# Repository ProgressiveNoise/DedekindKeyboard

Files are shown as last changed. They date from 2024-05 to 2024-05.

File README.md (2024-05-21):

# Dedekind, inspired by Cantor

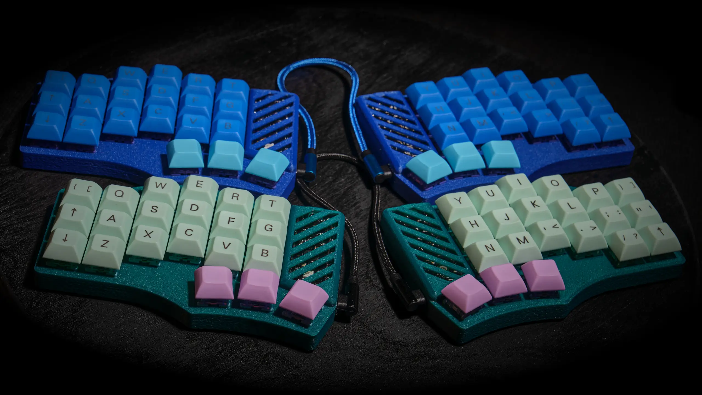
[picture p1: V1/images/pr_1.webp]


- Infinite set of silly mathematical jokes.

- Permissive Open Hardware Licence - do whatever you want with it.

- Not just PCBs, this repo contains STEP for a decent and easy to print case.
  Your build will be very solid.

- Reversible, no need to order 10 boards.

- MX Hotswap.

- Robust through-hole USB-C socket for interconnection:

    - Very reliable.

    - Does not fry MCU I/Os by design.

    - Cables are available in every shop on the planet.

- Optional extra protection circuit.

- RP2040 is a powerful and well-supported MCU.

- Easy to source parts.

This keyboard is compact, reliable, and relatively easy to build. It is
diodeless, the protection circuit is optional. Only the TH USB-C connector
could be an annoyance for an inexperienced builder, but that’s it. Everything
else should be smooth.

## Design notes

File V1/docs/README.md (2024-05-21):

## BOM

- 2 PCBs - necessary
- 2 Pico-like MCU boards - necessary
- 2 [USB-C TH connectors](https://www.aliexpress.com/item/4001044452764.html) - necessary
- 42 Kailh or Gateron MX sockets - necessary
- 2 0805 resistors - optional
- 2 323 protection devices - optional
- 4 20 pin sockets - optional

## PSBs
Everything is straightforward.

First, solder the MX sockets.

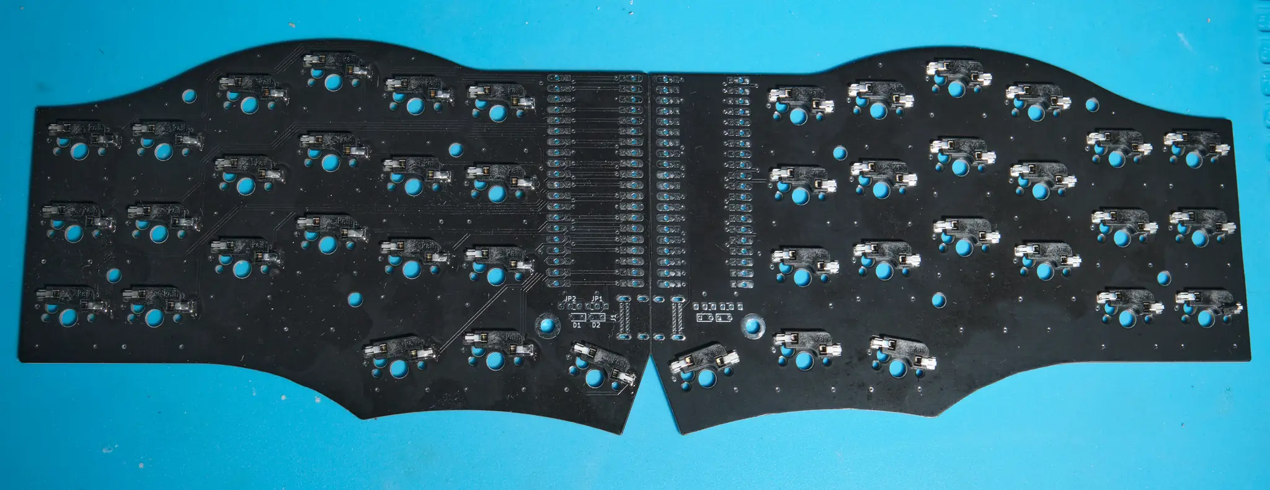
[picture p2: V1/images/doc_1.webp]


Then, solder protection circuit. You need TVS/ESD protection for 3.3V data
lines (I use the UCLAMP3301D) and some 0805 resistors. Their value is not very
important. Everything small enough, let’s say from 200 to 2k, should be fine.
You can skip this step, since the USB-C is a much safer connector than the
usual TRRS. If you decide to do so, just put jumpers instead of the resistors.
The white lines mark the default placement for the resistors/jumpers. Do not
forget about protection devices’ polarity as well.

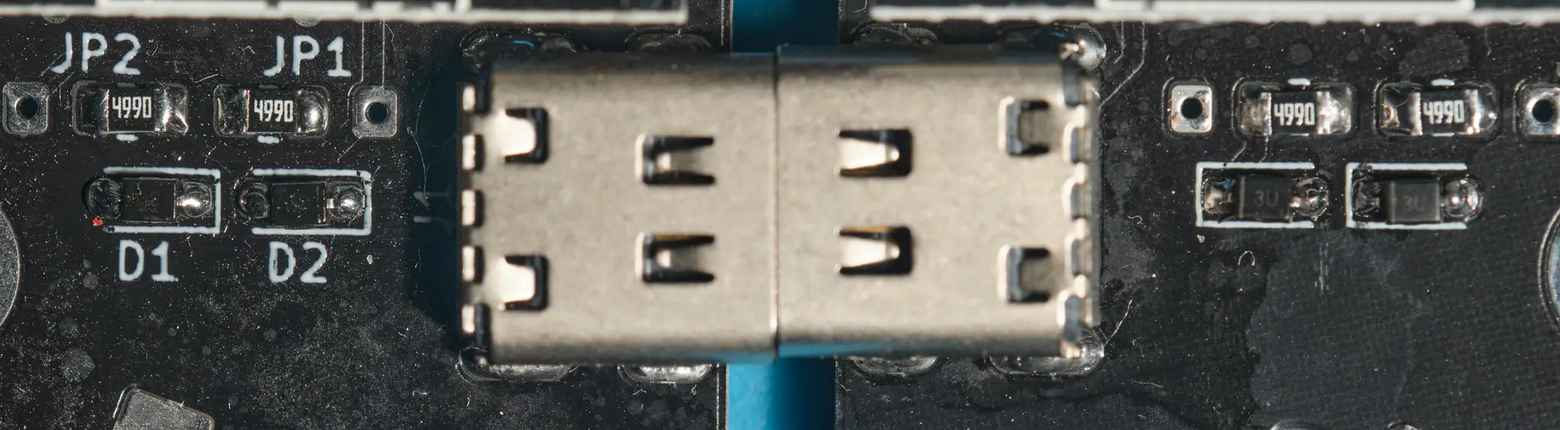
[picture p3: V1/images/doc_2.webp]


Solder the USB-C connector. Its “legs” may be too short for a thick PCBs, but
this is not a big issue. I fill the holes with soldering paste and then solder
“non-ground” part of the connector with a soldering iron. Good flux is your
best friend here! After that, use a slightly overheated iron for the ground
part of the connector, since the connector and copper pour suck a lot of heat.

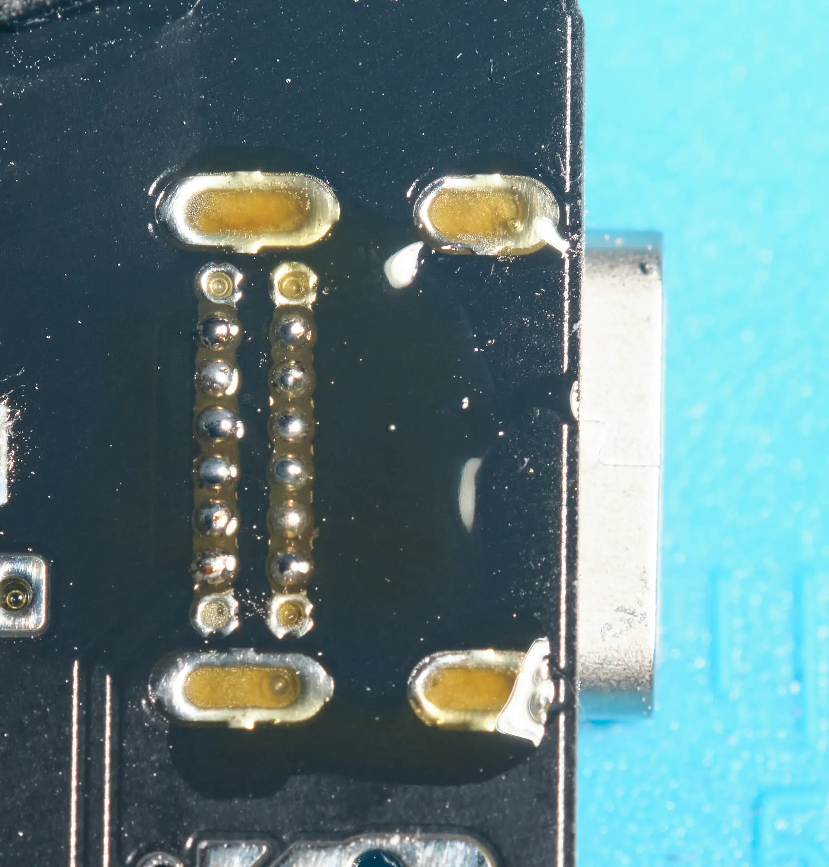
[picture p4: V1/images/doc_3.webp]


This is how it should look like in the end. This type of connection is very
safe and robust.

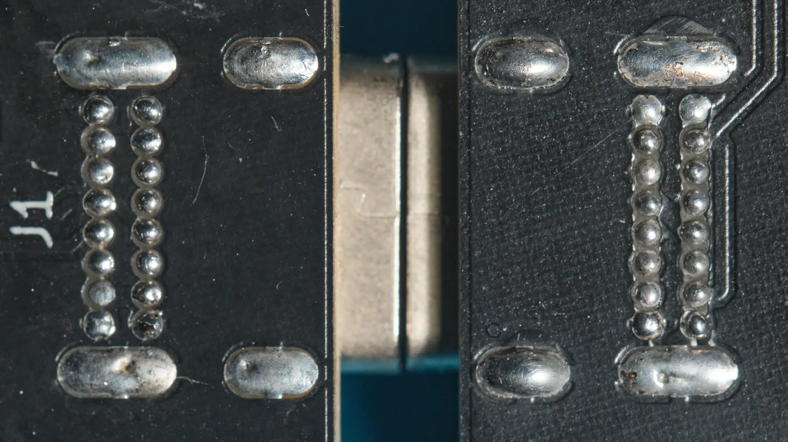
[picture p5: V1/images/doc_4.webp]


Then solder your MCU boards. The “official” case is designed for the 3.5 mm
sockets, but you can use whatever you like, of course, or no sockets at all.

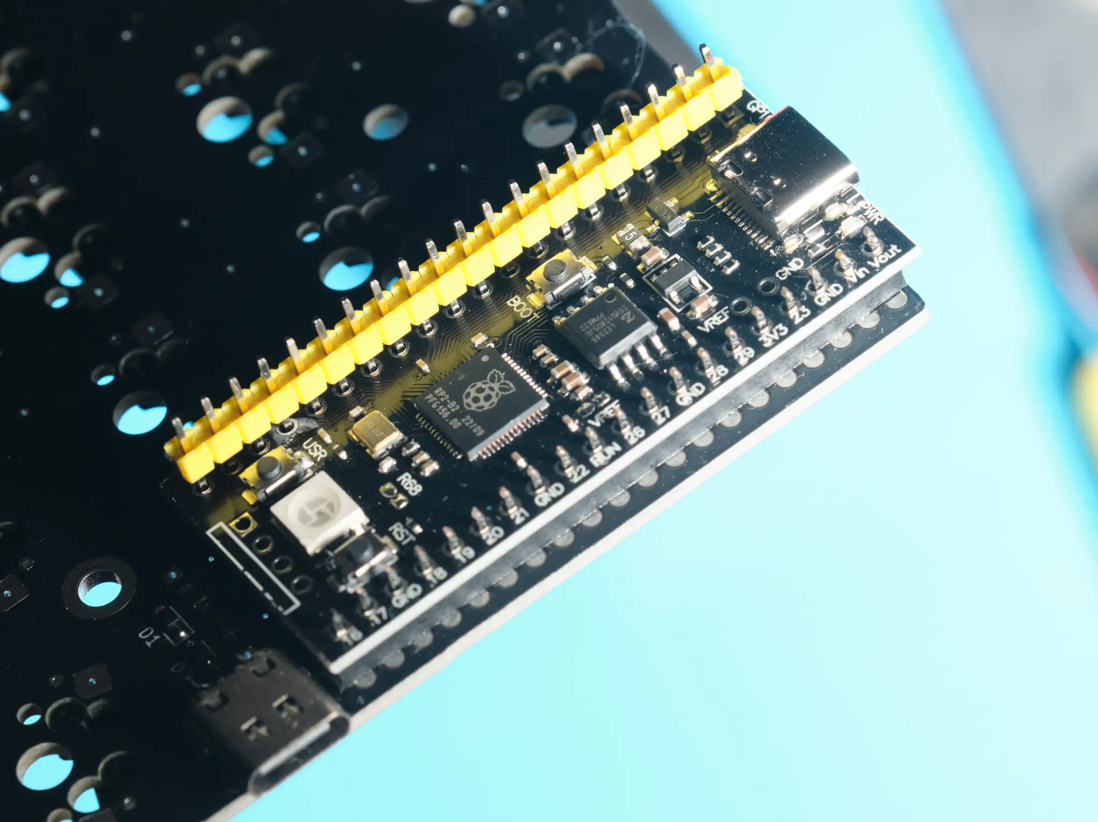
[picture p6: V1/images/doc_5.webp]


This is how it should look like from the top. 

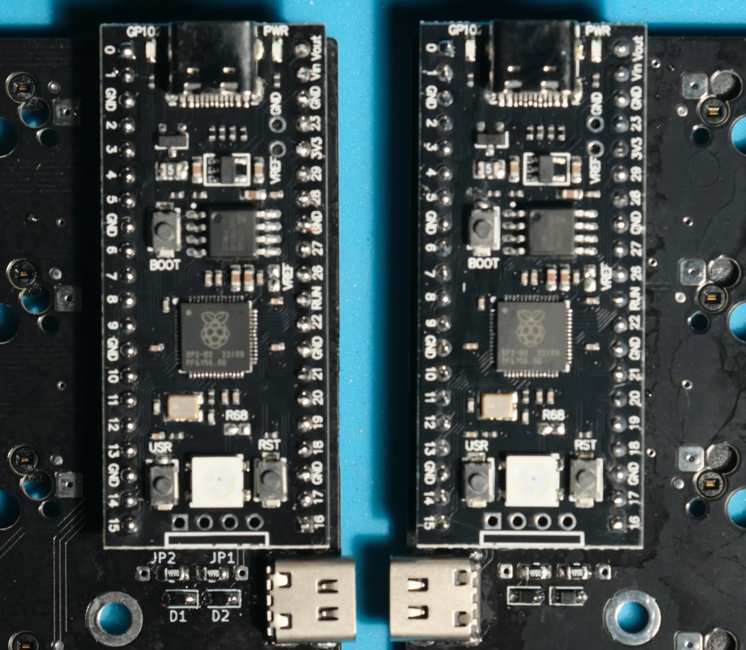
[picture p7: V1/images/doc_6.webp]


On the bottom, and on the bottom only, close the jumpers. Conical bent type
tips are particularly useful for it.

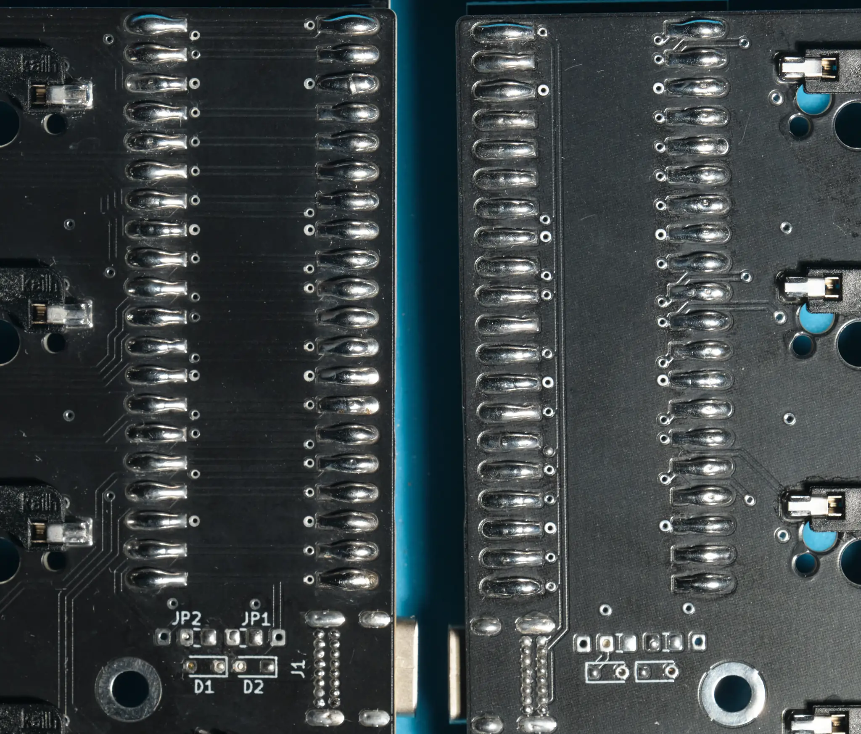
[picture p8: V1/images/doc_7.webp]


Now it is time to clean everything up.
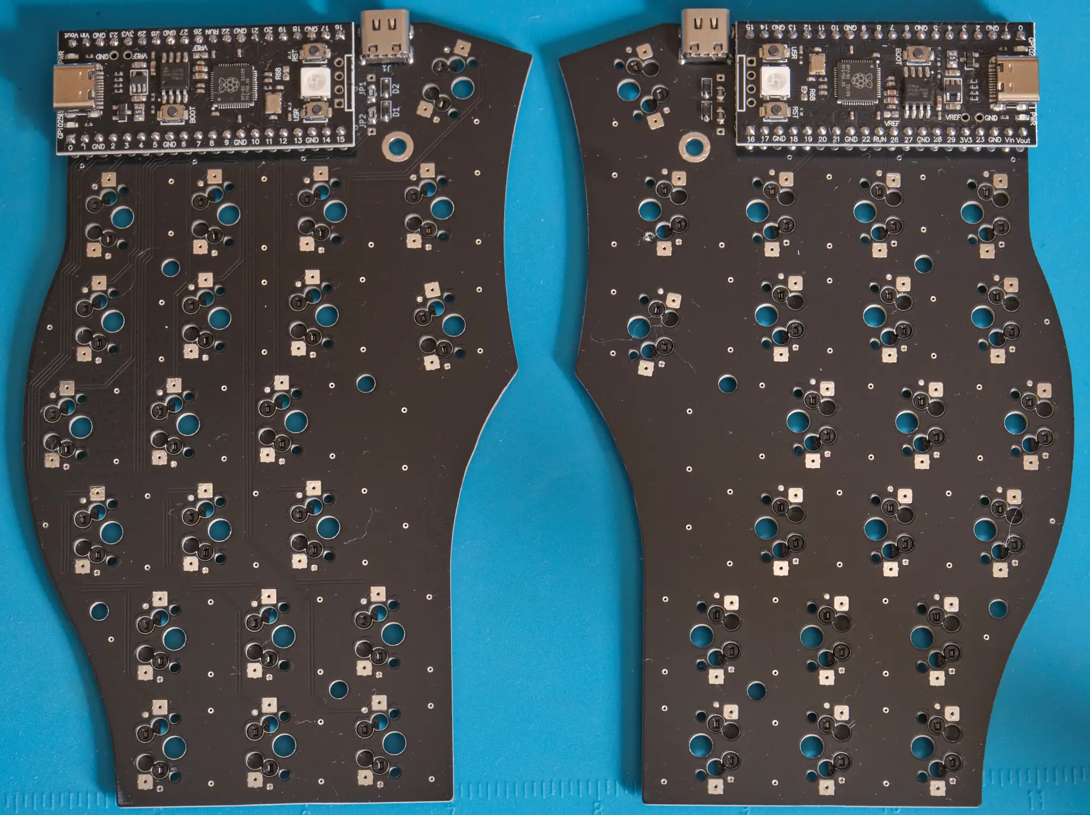
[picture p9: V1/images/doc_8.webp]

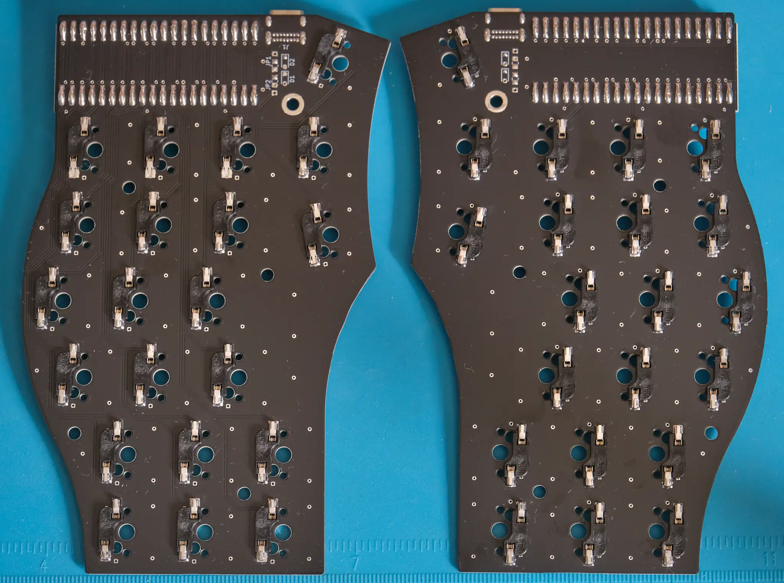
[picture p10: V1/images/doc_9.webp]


## Firmware

At the moment, only [KMK](https://kmkfw.io/) is supported since it is what I
use. I will add QMK support soon.

- Drag and drop [CircuitPyton for the Pico](https://circuitpython.org/board/raspberry_pi_pico/).
  [Official guide](https://learn.adafruit.com/welcome-to-circuitpython/installing-circuitpython).
- Copy the kmk directory from the [official repo](https://github.com/KMKfw/kmk_firmware) to 
    the CIRCUITPY “flash drive”.
- Copy kb.py and main.py from [this repo](../kmk/) to the same place.
- Then rename the “drives” as “DEDR” for the right half and “DEDL” for the left
    half.

The keyboard should work, but its configuration is beyond the scope of
this guide. Follow the official documentation for KMK and CP.

## Case

I provide an “official“ case for this keyboard. It is a straightforward print,
but the frame around the MCU board is susceptible to warping, so use
warp-preventing settings in your slicer, or even a brim. It is better to be
safe than sorry. The MCU cover is optional. Glue it to the top case if you want
to use it.

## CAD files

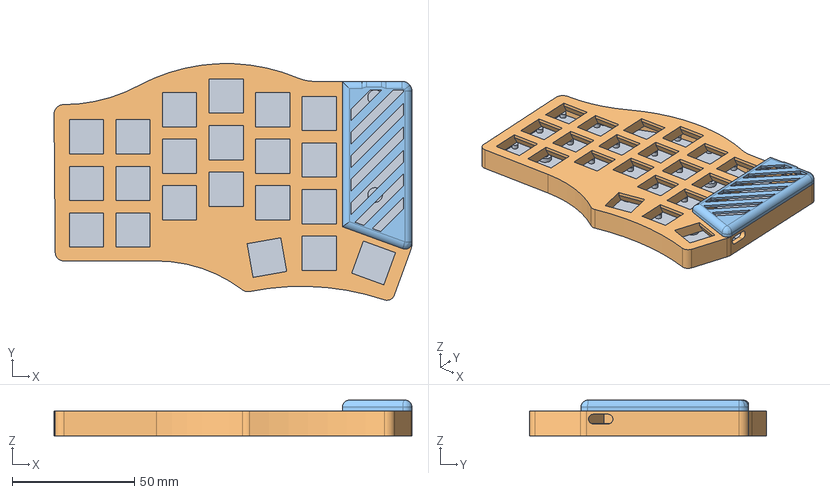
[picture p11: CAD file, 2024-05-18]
V1/case/Dedekind_MX_Case_V1.step
146.5 x 96.8 x 14.7 mm
Bottom
Plate
MCU Cover

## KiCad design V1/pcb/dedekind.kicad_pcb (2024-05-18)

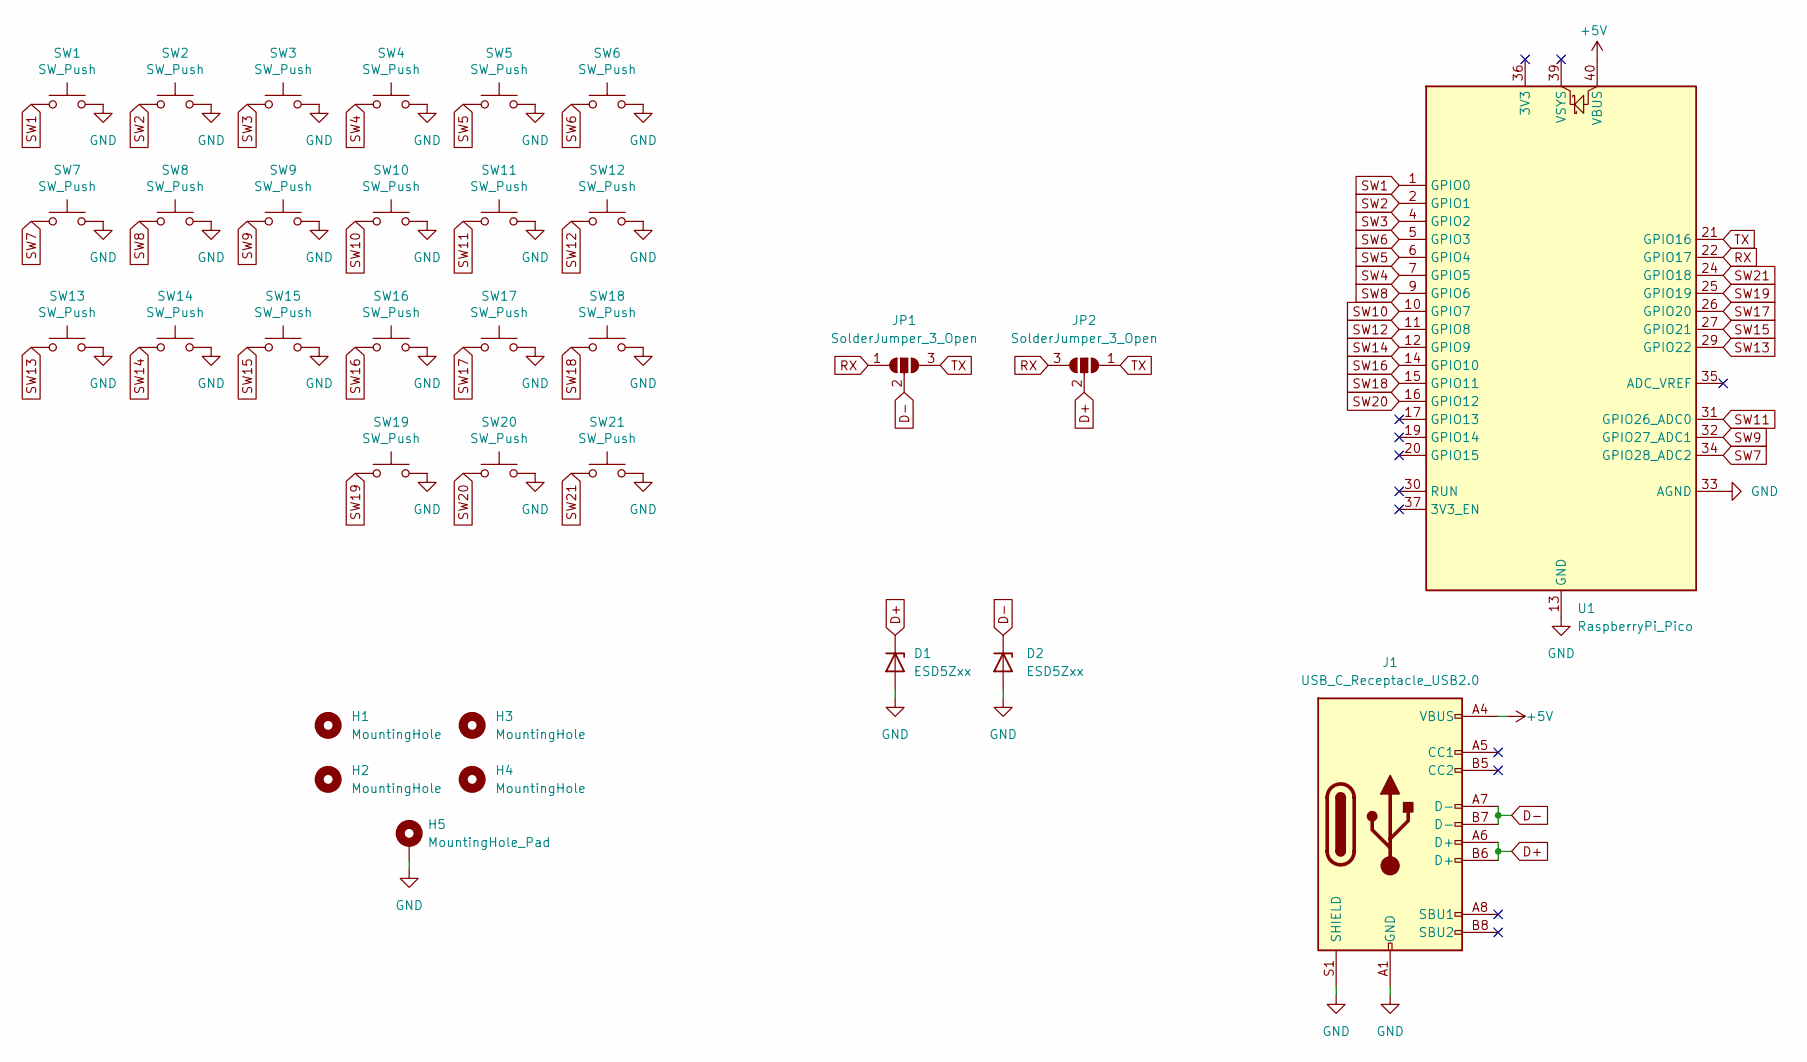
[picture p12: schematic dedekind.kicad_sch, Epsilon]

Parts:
D1, D2: ESD5Zxx; D_SOD-323_TH_HandSoldering
H1, H2, H3, H4: MountingHole; MountingHole_3.2mm_M3
H5: MountingHole_Pad; MountingHole_3.2mm_M3_DIN965_Pad
J1: USB_C_Receptacle_USB2.0; USB_C_Receptacle_JBL
JP1, JP2: SolderJumper_3_Open; R_0805_2012Metric_Pad1.20x1.40mm_Jumper_HandSolder
SW1, SW2, SW3, SW4, SW5, SW6, SW7, SW8, SW9, SW10, SW11, SW12, SW13, SW14, SW15, SW16, SW17, SW18, SW19, SW20, SW21: SW_Push; SW_Hotswap_Kailh_MX_DS_1.00u
U1: RaspberryPi_Pico; RaspberryPi_Pico_Common_Reversable

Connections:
+5V: J1.A4 (VBUS), J1.A9 (VBUS), J1.B4 (VBUS), J1.B9 (VBUS), U1.40 (VBUS)
D+: D1.1 (K), J1.A6 (D+), J1.B6 (D+), JP2.2 (C)
D-: D2.1 (K), J1.A7 (D-), J1.B7 (D-), JP1.2 (C)
GND: D1.2 (A), D2.2 (A), H5.1, J1.A1 (GND), J1.A12 (GND), J1.B1 (GND), J1.B12 (GND), J1.S1 (SHIELD), SW1.2, SW2.2, SW3.2, SW4.2, SW5.2, SW6.2, SW7.2, SW8.2, SW9.2, SW10.2, SW11.2, SW12.2, SW13.2, SW14.2, SW15.2, SW16.2, SW17.2, SW18.2, SW19.2, SW20.2, SW21.2, U1.3 (GND), U1.8 (GND), U1.13 (GND), U1.18 (GND), U1.23 (GND), U1.28 (GND), U1.33 (AGND), U1.38 (GND)
RX: JP1.1 (A), JP2.3 (B), U1.22 (GPIO17)
SW1: SW1.1, U1.1 (GPIO0)
SW2: SW2.1, U1.2 (GPIO1)
SW3: SW3.1, U1.4 (GPIO2)
SW4: SW4.1, U1.7 (GPIO5)
SW5: SW5.1, U1.6 (GPIO4)
SW6: SW6.1, U1.5 (GPIO3)
SW7: SW7.1, U1.34 (GPIO28_ADC2)
SW8: SW8.1, U1.9 (GPIO6)
SW9: SW9.1, U1.32 (GPIO27_ADC1)
SW10: SW10.1, U1.10 (GPIO7)
SW11: SW11.1, U1.31 (GPIO26_ADC0)
SW12: SW12.1, U1.11 (GPIO8)
SW13: SW13.1, U1.29 (GPIO22)
SW14: SW14.1, U1.12 (GPIO9)
SW15: SW15.1, U1.27 (GPIO21)
SW16: SW16.1, U1.14 (GPIO10)
SW17: SW17.1, U1.26 (GPIO20)
SW18: SW18.1, U1.15 (GPIO11)
SW19: SW19.1, U1.25 (GPIO19)
SW20: SW20.1, U1.16 (GPIO12)
SW21: SW21.1, U1.24 (GPIO18)
TX: JP1.3 (B), JP2.1 (A), U1.21 (GPIO16)

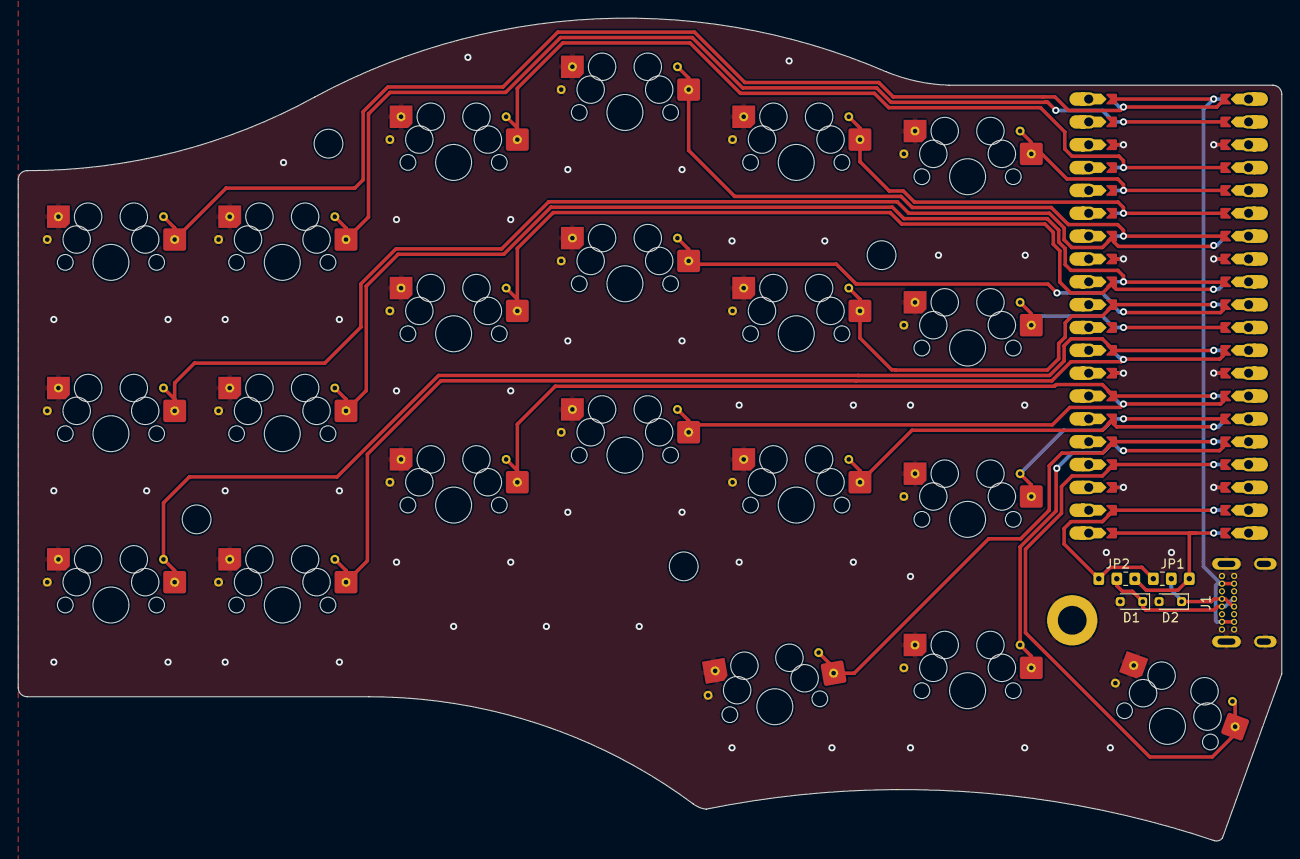
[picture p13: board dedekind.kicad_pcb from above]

Board: 2 copper layers, 140.5 x 91.5 mm, 32 parts (0 on the bottom side), 27 nets.

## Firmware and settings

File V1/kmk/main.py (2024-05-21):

import board

from kb import KMKKeyboard, is_right

from kmk.keys import KC
from kmk.modules.layers import Layers
from kmk.modules.split import Split, SplitSide

from kmk.modules.holdtap import HoldTap
from kmk.modules.combos import Combos, Chord
from kmk.handlers.sequences import simple_key_sequence as sks

keyboard = KMKKeyboard()

# Split
split_side = SplitSide.RIGHT if is_right else SplitSide.LEFT

split = Split(
    split_side=split_side,
    split_target_left=True,
    uart_interval=20,
    data_pin=board.GP17,  # RX
    data_pin2=board.GP16,  # TX
    uart_flip=False,
    use_pio=False,
)

keyboard.modules.append(split)

# Layers
layers = Layers()
keyboard.modules.append(layers)


# HoldTap
holdtap = HoldTap()
holdtap.tap_time = 175
keyboard.modules.append(holdtap)


# Key names
_______ = KC.TRNS
XXXXXXX = KC.NO

# Mod-taps and layer-taps
# Left hand HRM
A_SFT = KC.HT(KC.A, KC.LSFT)
S_CTR = KC.HT(KC.S, KC.LCTRL)
D_GUI = KC.HT(KC.D, KC.LGUI)
V_VIM = KC.LT(3, KC.V)
F_SYM = KC.LT(1, KC.F)

# Left hand thumbs
SPC_NAV = KC.LT(2, KC.SPC)
TAB_ALT = KC.HT(KC.TAB, KC.LALT)

# Right hand HRM
J_SYM = KC.LT(1, KC.J)
K_GUI = KC.HT(KC.K, KC.RGUI)
L_CTR = KC.HT(KC.L, KC.RCTRL)
M_VIM = KC.LT(3, KC.M)
SCLN_SFT = KC.HT(KC.SCLN, KC.RSFT)

# Right hand thumbs
DEL_ALT = KC.HT(KC.DEL, KC.RALT)
ENT_NAV = KC.LT(2, KC.ENT)
BSP_TMX = KC.LT(4, KC.BSPC)

# Vi-style combos
combos = Combos()

combos.combos = [
    Chord((V_VIM, M_VIM), KC.TG(3)),  # Toggle quasi-Vim layer
    Chord((M_VIM, KC.G), sks((KC.EQL, KC.RABK))),  # => symbol
    Chord((M_VIM, KC.T), sks((KC.MINS, KC.RABK))),  # -> symbol
    Chord((KC.N, KC.G), sks((KC.EXLM, KC.EQL))),  # != symbol
]

keyboard.modules.append(combos)

NXT_W = KC.LCTRL(KC.RIGHT)
PRV_W = KC.LCTRL(KC.LEFT)
O_INP = sks((KC.END, KC.ENT, KC.TO(0)))
I_INP = KC.TO(0)
U_UND = KC.LCTRL(KC.Z)

# TMUX
TM_SCR0 = sks((KC.LCTRL(KC.B), KC.N0))
TM_SCR1 = sks((KC.LCTRL(KC.B), KC.N1))
TM_SCR2 = sks((KC.LCTRL(KC.B), KC.N2))
TM_SCR3 = sks((KC.LCTRL(KC.B), KC.N3))
TM_SCR4 = sks((KC.LCTRL(KC.B), KC.N4))
TM_SCR5 = sks((KC.LCTRL(KC.B), KC.N5))
TM_SCR6 = sks((KC.LCTRL(KC.B), KC.N6))
TM_CRT = sks((KC.LCTRL(KC.B), KC.C))

# fmt: off
keyboard.keymap = [
    [  # QWERTY
       #XXXXXXX,  XXXXXXX,  XXXXXXX,  XXXXXXX,  XXXXXXX,  XXXXXXX,                      XXXXXXX,  XXXXXXX,  XXXXXXX,  XXXXXXX,  XXXXXXX,  XXXXXXX, \
        KC.LBRC,  KC.Q,     KC.W,     KC.E,     KC.R,     KC.T,                         KC.Y,     KC.U,     KC.I,     KC.O,     KC.P,     KC.RBRC, \
        KC.UNDS,  A_SFT,    S_CTR,    D_GUI,    F_SYM,    KC.G,                         KC.H,     J_SYM,    K_GUI,    L_CTR,    SCLN_SFT, KC.DQT,  \
        KC.COLN,  KC.Z,     KC.X,     KC.C,     V_VIM,    KC.B,                         KC.N,     M_VIM,    KC.COMM,  KC.DOT,   KC.SLSH,  KC.BSLS, \
                                                KC.ESC,   SPC_NAV,  TAB_ALT,  DEL_ALT,  ENT_NAV,  BSP_TMX,
    ],
    [  # SYMBOLS
       #XXXXXXX,  XXXXXXX,  XXXXXXX,  XXXXXXX,  XXXXXXX,  XXXXXXX,                      XXXXXXX,  XXXXXXX,  XXXXXXX,  XXXXXXX,  XXXXXXX,  XXXXXXX, \
        KC.SLSH,  KC.HASH,  KC.N4,    KC.N5,    KC.N6,    KC.MINS,                      KC.CIRC,  KC.RCBR,  KC.LCBR,  KC.DLR,   KC.AT,    KC.TILD, \
        KC.PERC,  KC.N0,    KC.N1,    KC.N2,    KC.N3,    KC.EQL,                       KC.GRV,   KC.RPRN,  KC.LPRN,  KC.RBRC,  KC.LBRC,  KC.QUOT, \
        KC.DOT,   KC.ASTR,  KC.N7,    KC.N8,    KC.N9,    KC.PLUS,                      KC.EXLM,  KC.RABK,  KC.LABK,  KC.AMPR,  KC.QUES,  KC.PIPE, \
                                                _______,  _______,  _______,  _______,  _______,  _______,
    ],
    [  # NAVIGATION
       #XXXXXXX,  XXXXXXX,  XXXXXXX,  XXXXXXX,  XXXXXXX,  XXXXXXX,                      XXXXXXX,  XXXXXXX,  XXXXXXX,  XXXXXXX,  XXXXXXX,  XXXXXXX, \
        XXXXXXX,  XXXXXXX,  XXXXXXX,  XXXXXXX,  XXXXXXX,  XXXXXXX,                      XXXXXXX,  XXXXXXX,  XXXXXXX,  XXXXXXX,  XXXXXXX,  XXXXXXX, \
        XXXXXXX,  XXXXXXX,  KC.LEFT,  KC.UP,    KC.RIGHT, XXXXXXX,                      KC.LEFT,  KC.DOWN,  KC.UP,    KC.RIGHT, XXXXXXX,  XXXXXXX, \
        XXXXXXX,  XXXXXXX,  XXXXXXX,  KC.DOWN,  XXXXXXX,  XXXXXXX,                      XXXXXXX,  XXXXXXX,  XXXXXXX,  XXXXXXX,  XXXXXXX,  XXXXXXX, \
                                                _______,  _______,  _______,  _______,  _______,  _______,
    ],
    [  # QUASI-VIM
       #XXXXXXX,  XXXXXXX,  XXXXXXX,  XXXXXXX,  XXXXXXX,  XXXXXXX,                      XXXXXXX,  XXXXXXX,  XXXXXXX,  XXXXXXX,  XXXXXXX,  XXXXXXX, \
        XXXXXXX,  XXXXXXX,  NXT_W,    XXXXXXX,  XXXXXXX,  XXXXXXX,                      XXXXXXX,  U_UND,    I_INP,    O_INP,    XXXXXXX,  XXXXXXX, \
        XXXXXXX,  XXXXXXX,  KC.LEFT,  KC.PGDN,  KC.RIGHT, XXXXXXX,                      KC.LEFT,  KC.DOWN,  KC.UP,    KC.RIGHT, XXXXXXX,  XXXXXXX, \
        XXXXXXX,  XXXXXXX,  XXXXXXX,  KC.DOWN,  V_VIM,    PRV_W,                        XXXXXXX,  M_VIM,    XXXXXXX,  XXXXXXX,  XXXXXXX,  XXXXXXX, \
                                                _______,  _______,  _______,  _______,  _______,  _______,
    ],
    [  # TMUX
       #XXXXXXX,  XXXXXXX,  XXXXXXX,  XXXXXXX,  XXXXXXX,  XXXXXXX,                      XXXXXXX,  XXXXXXX,  XXXXXXX,  XXXXXXX,  XXXXXXX,  XXXXXXX, \
        XXXXXXX,  XXXXXXX,  TM_SCR4,  TM_SCR5,  TM_SCR6,  XXXXXXX,                      XXXXXXX,  XXXXXXX,  XXXXXXX,  XXXXXXX,  XXXXXXX,  XXXXXXX, \
        XXXXXXX,  TM_SCR0,  TM_SCR1,  TM_SCR2,  TM_SCR3,  XXXXXXX,                      XXXXXXX,  XXXXXXX,  XXXXXXX,  XXXXXXX,  XXXXXXX,  XXXXXXX, \
        XXXXXXX,  XXXXXXX,  XXXXXXX,  TM_CRT,   XXXXXXX,  XXXXXXX,                      XXXXXXX,  XXXXXXX,  XXXXXXX,  XXXXXXX,  XXXXXXX,  XXXXXXX, \
                                                _______,  _______,  _______,  _______,  _______,  _______,
    ]
]
# fmt: on

if __name__ == '__main__':
    keyboard.go()

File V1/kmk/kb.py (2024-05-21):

import board
from storage import getmount
from kmk.kmk_keyboard import KMKKeyboard as _KMKKeyboard
from kmk.scanners.keypad import KeysScanner

name = str(getmount("/").label)
is_right = True if name.endswith("R") else False

# fmt: off
_KEY_CFG_LEFT = [
    board.GP0, board.GP1, board.GP2, board.GP5, board.GP4, board.GP3,
    board.GP28, board.GP6, board.GP27, board.GP7, board.GP26, board.GP8,
    board.GP22, board.GP9, board.GP21, board.GP10, board.GP20, board.GP11,
    board.GP19, board.GP12, board.GP18,
]

_KEY_CFG_RIGHT = [
    board.GP3, board.GP4, board.GP5, board.GP2, board.GP1, board.GP0,
    board.GP8, board.GP26, board.GP7, board.GP27, board.GP6, board.GP28,
    board.GP11, board.GP20, board.GP10, board.GP21, board.GP9, board.GP22,
    board.GP18, board.GP12, board.GP19,
]
# fmt: on


class KMKKeyboard(_KMKKeyboard):
    def __init__(self):
        self.matrix = KeysScanner(
            pins=_KEY_CFG_RIGHT if is_right else _KEY_CFG_LEFT
        )

    # fmt: off
    coord_mapping = [
        0,  1,  2,  3,  4,  5,   21, 22, 23, 24, 25, 26,
        6,  7,  8,  9, 10, 11,   27, 28, 29, 30, 31, 32,
       12, 13, 14, 15, 16, 17,   33, 34, 35, 36, 37, 38, # noqa
                   18, 19, 20,   39, 40, 41 # noqa 
    ]
